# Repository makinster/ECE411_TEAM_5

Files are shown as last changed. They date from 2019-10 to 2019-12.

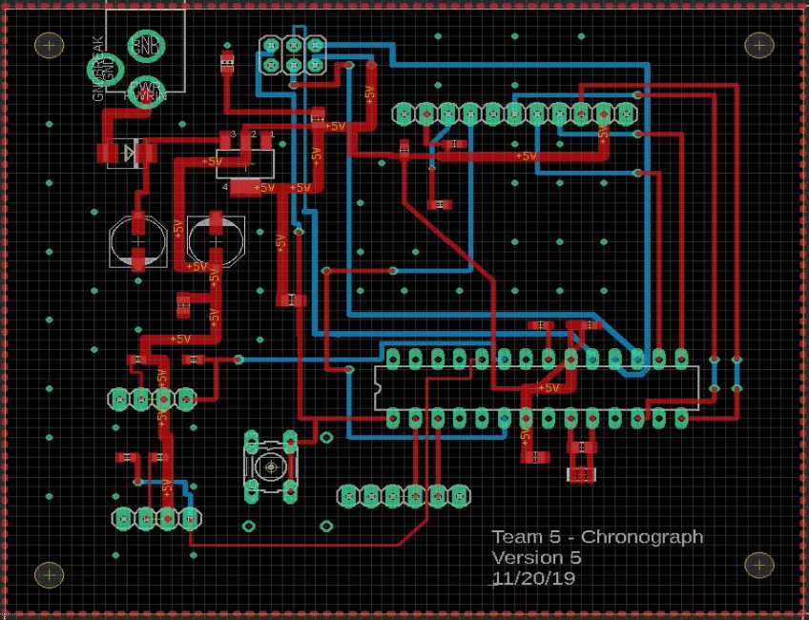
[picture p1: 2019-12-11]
Design Log/5_Implemtation - Board.PNG

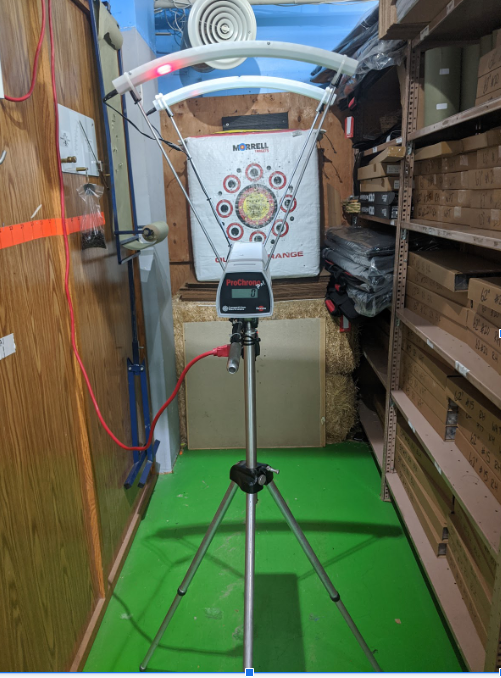
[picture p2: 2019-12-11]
Design Log/6_Testing at Archers Afield.PNG

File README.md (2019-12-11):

# ECE411 Team 5
Team 5 Project - Shooting Chronograph
Members: Sean Schorzman, Kelly Makinster, Jaeyoon Lee, Jianyu Hao

https://drive.google.com/drive/u/1/folders/1vWiaBcHWNWfePrjI9KzBYRflg-hPmRDC

**************************************************************************************

   Practicum project - Ballistic Chronograph
   
   ECE 411
   Fall 2019
   
   Team 5: Sean Schorzman, Jaeyoon Lee, Jianyu Hao, Kelly Makinster
                                                                                     
   Description: Displays the speed in fps of an object that passes through a
                set of IR detector sensors. IR sensors are arranged in a PVC
                pipe 8 inches apart with an IR light directily accross from
                each sensor. Upon passing sensor 1, a timer begins and waits
                until either sensor 2 detects an object or a timeout occurs.
                An additional push button input is used to reset IR detector
                light levels in order to adjust detection sensitivity.
                                                                                  
                                                                                  
 **************************************************************************************

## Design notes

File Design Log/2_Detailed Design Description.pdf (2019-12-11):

Module | Shooting Chronograph
Inputs | IR Sensor 1, IR Sensor 2, Power - USB
Outputs | LCD Screen, Sensor Output (Time between clocks)
Functionality | A flying projectile (BB, dart) will pass sensor 1. start clock, pass sensor 2, stop the clock. The time passed between the sensor interruptions will be displayed on an LCD screen

Shooting Chronograph: Level 0

Visual Paradigm Online Diagrams Express Edition

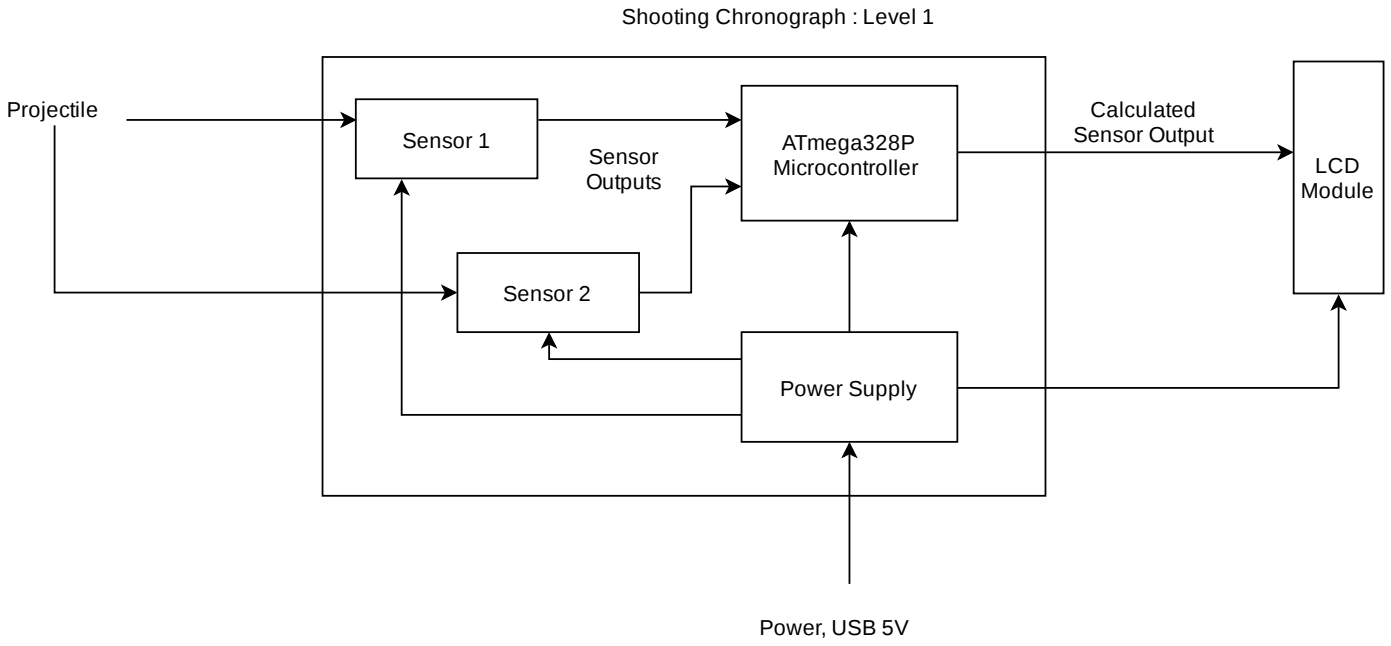
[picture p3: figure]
Power Supply; ATmega328P Microcontroller; Sensor 2; Sensor 1; Sensor Outputs; Calculated Sensor Output; Projectile; LCD Module; Shooting Chronograph : Level 1; Power, USB 5V

IR Sensor 1

Power
Supply
Projectile | Sensor Output
Module(s) | IR Sensor 1 / IR Sensor 2
Inputs | Projectile
Outputs | Sensor Output sent to ATmega328P Microcontroller

Functionality

The sensor will change sensor value if a projectile blocks emitter-detector communication

ATmega 328P
Microcontroller

Sensor 1 Output

Sensor 2 Output

Power
Supply

Calculated
Sensor Output
Module | ATmega 328P Microcontroller
Inputs | IR Sensor 1 and IR Sensor 2 Outputs
Outputs | Calculated Sensor Output - Velocity of Projectile
Functionality | The microcontroller will start the clock when sensor 1 is interrupted, and stop the clock once sensor 2 is interrupted. The microcontroller will calculate the speed of the projectile and send that data out.

LCD

Speed of
Projectile

Power
Supply

Calculated
Sensor
Output
Module | LCD

Power Supply

USB

5 DC Volts

Power Supply: Level 1

IR Sensor 1 and Sensor 2: Level 1

LCD Display: Level 1

ATmega 328P Microcontroller: Level 1

Module | Power Supply

Inputs | Microcontroller Sensor Calculations
Outputs | Speed of Projectile

Functionality

The LCD screen will display the speed of the projectile.

Inputs | USB
Outputs | 5 DC Volts

Functionality

Power supply via
USB Cable

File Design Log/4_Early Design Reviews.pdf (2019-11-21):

ECE 411

Practicum Week 7 HW Part 1

Design Reviews

Team 5: Jianyu Hao, Jaeyoon Lee, Kelly Makinster, Sean Schorzman

11/20/19

From Group 17:

- AVCC needs power + cap to ground
- AREF needs cap to ground
- LCD Pin 10 needs Volts
- Give names to J2

From Eric

- Make sure Team name, date, version is on silk screen
- Thicken 5V
- Trace 0 – ground supplies – Fix it
- Refer to AREF datasheet
- Power regulator needs to take in 5 volts
- 6 pin header and Display LCD should be separated a little

From Andrew:

- 100 nF cap AREF – cap to ground
- Bypass AVCC – cap to ground
- Ground symbol for each LCD
- Via ‘GND’ stitch two ground planes
- Din - +doc – dimensions
- J2 Blue wire – change top larger (Red)
- PD2 – serial adapter – delete Pin 1 on J2
- Bypass cap literally next to Pin C6
- Drill holes too small – Make larger

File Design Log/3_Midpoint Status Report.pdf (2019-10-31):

ECE 411

Practicum Homework #4: Current Status Report

Team 5: Jianyu Hao, Jaeyoon Lee, Kelly Makinster, Sean Schorzman

10/30/19

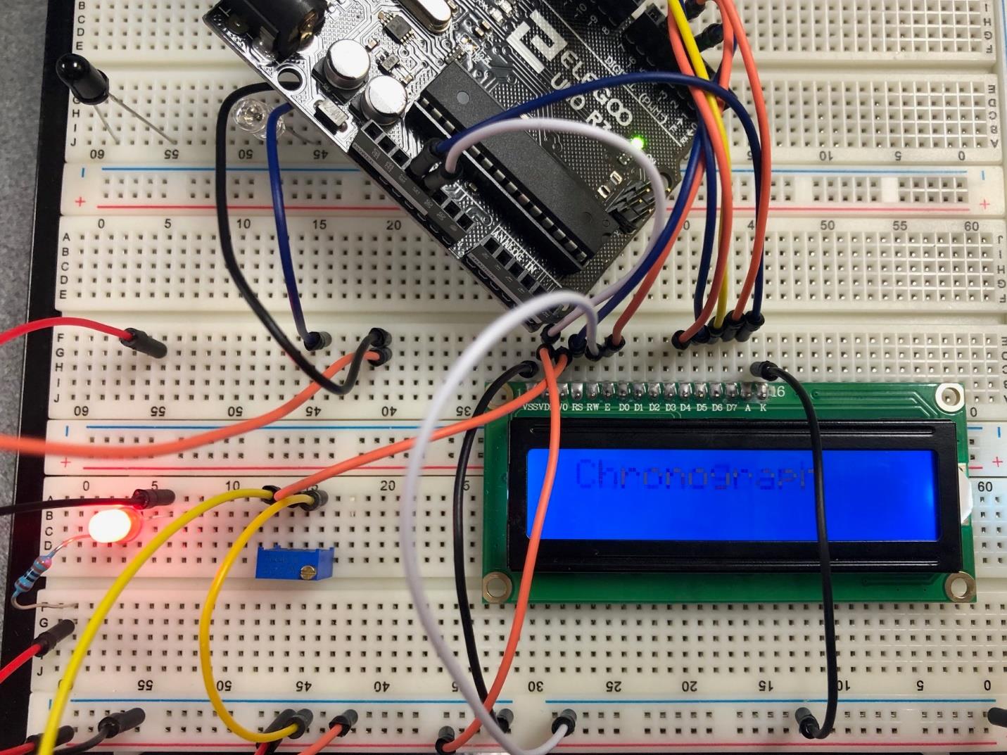
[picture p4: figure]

Our team has acquired most of the essential parts needed for the project in time to be assembled. We have also ensured the parts’ functionality to make sure they work when assembled on the breadboard together. With the preliminary schematic designed for our project, we built our first prototype on a breadboard at its rough stage. Currently, we’ve completed most of the assembly and double checked to make sure the parts function as they should. More research will be conducted in the upcoming week to complete the prototype and begin the first testing.

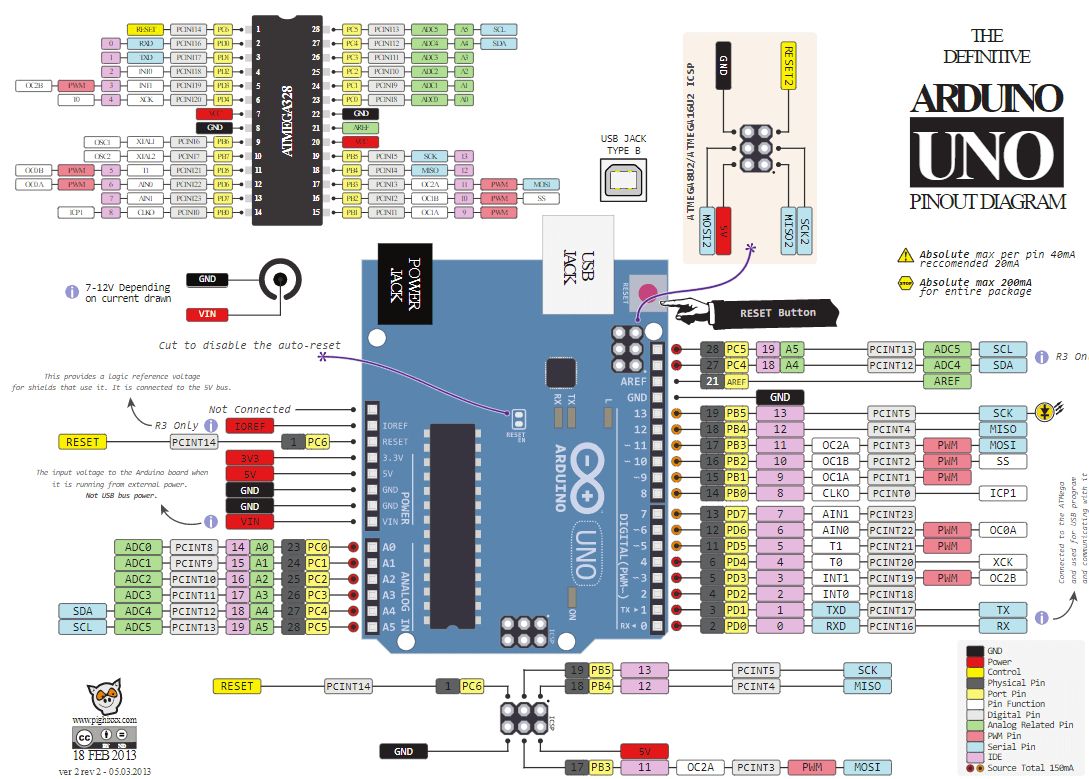
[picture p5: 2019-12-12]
Arduino Pinout.png

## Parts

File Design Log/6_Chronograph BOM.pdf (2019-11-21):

Chronograph BOM

Qty | Value | Parts | Manufacturer | Mfr. Part Number | Description
6 | 100n | C2, C4, C5, C6, C7, C8 | Samsung | CL21B104KBCNNNC | CAP CER 0.1UF 50V X7R 0805
2 | 47u | C1, C3 | NICHICON | UWT1H470MCL1GS | CAP ALUM 47UF 20% 50V SMD
1 | 10 | R11 | Yageo | RC0402FR-0710RL | RES SMD 10 OHM 1% 1/16W 0402
1 | 100 | R12 | Yageo | RC0402FR-07100RL | RES SMD 100 OHM 1% 1/16W 0402
2 | 1K | R3, R6 | Yageo | RC0805FR-071KL | RES SMD 1K OHM 1% 1/8W 0805
3 | 10K | R1, R13, R10 | Yageo | RC0805FR-0710KL | RES SMD 10K OHM 1% 1/8W 0805
1 | 1M | R2 | Yageo | RC0402FR-071ML | RES SMD 1M OHM 1% 1/16W 0402
1 | 3x2 M | J1 | Harwin Inc. | M20-9980346 | CONN HEADER VERT 6POS 2.54MM
1 | 1x6 | J2 | Würth Elektronik | 61300611121 | CONN HEADER VERT 6POS 2.54MM
2 | 1x4 | IR_PAIR1, IR_PAIR2 Würth Elektronik | 61300411121 | CONN HEADER VERT 4POS 2.54MM
1 | | R_BUTTON | B3F-1000 | OMRON SWITCH
1 | ATMEGA328P-PU | U4 | Microchip Technology | ATMEGA328-PU | IC MCU 8BIT 32KB FLASH 28DIP
1 | CSTCE16M0V53-R0 16MHZ | X1 | Murata Electronics | CSTCE16M0V53-R0 | CERAMIC RES 16.0000MHZ 15PF SMD
1 | EA_DIP | DIS1 | Lumex Opto/Components Inc. | LCM-S01602DTR/M | LCD MODULE 16X2 CHARACTER
1 | GREEN | LED1 | Würth Elektronik | 150080GS75000 | LED GREEN CLEAR 0805 SMD
1 | M7 | D1 | Diodes Incorporated | B340AE-13 | DIODE SCHOTTKY 40V 2A SMA
1 | NCP1117ST50T3G | U1 | ON Semiconductor | MC33375ST-5.0T3G | IC REG LINEAR 5V 300MA SOT223
2 | SFH206 | D6, D7 | Vishay Semiconductor Opto Division | BPW24R | SENSOR PHOTODIODE 900NM RADIAL
2 | SFH482 | D2, D3 | Vishay Semiconductor Opto Division | TSPF6200 | EMITTER IR 890NM 100MA RADIAL
1 | POWER_JACK | J4 | CUI Devices | PJ-102B | CONN PWR JACK 2.5X5.5MM SOLDER

PARTS NOT FROM DIGIKEY
PARTS ALREADY OWNED

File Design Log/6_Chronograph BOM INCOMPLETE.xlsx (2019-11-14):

Qty | Value | Device | Manufacturer | Parts | Mfr. Part Number | Description | Device
1 |  | PINHD-1X6 |  | J2 |  | PIN HEADER | PINHD-1X6
6 |  | R-US_0204/7 |  | R4, R5, R6, R7, R8, R9 |  | RESISTOR, American symbol | R-US_0204/7
2 | 100n | C-EUC0805 | SAMSUNG | C2, C6 | CL21B104KBCNNNC | CAP CER 0.1UF 50V X7R 0805 | C-EUC0805
1 | 10K | R-US_R0805 |  | R1 |  | RESISTOR, American symbol | R-US_R0805
1 | 1K | R-US_R0805 |  | R3 |  | RESISTOR, American symbol | R-US_R0805
1 | 1M | R-US_R0805 |  | R2 |  | RESISTOR, American symbol | R-US_R0805
1 | 3x2 M | PINHD-2X3 |  | J1 |  | PIN HEADER | PINHD-2X3
2 | 47u | CPOL-EUD | NICHICON | C1, C3 | UWT1H470MCL1GS | CAP ALUM 47UF 20% 50V SMD | CPOL-EUD
1 | ATMEGA328P-PU | ATMEGA328P-PU |  | U4 |  | MICROCONTROLLER | ATMEGA328P-PU
1 | CSTCE16M0V53-R0 16MHZ | RESONATORMU |  | X1 |  |  | RESONATORMU
1 | EA_DIP | EA_DIP |  | DIS1 |  | LCD-MODUL 2x16 - 6,68mm, INKL. KONTROLLER HD44780 | EA_DIP
1 | GREEN | LEDCHIP-LED0805 |  | LED1 |  | LED | LEDCHIP-LED0805
1 | M7 | DIODE-SMB |  | D1 |  | DIODE | DIODE-SMB
1 | NCP1117ST50T3G | MC33269ST-3.3T3 |  | U1 |  | Adjustable Output Low Dropout Voltage Regulator 800 mA | MC33269ST-3.3T3
1 | PC16S | PC16S |  | 20K |  | POTENTIOMETER | PC16S
1 | POWER_JACK | POWER_JACK |  | J4 |  | Power Jack Connector | POWER_JACK
4 | SFH482 | SFH482 |  | D2, D3, D4, D5 |  | IR LED | SFH482
4 | STAND-OFF | STAND-OFF |  | H1, H2, H3, H4 |  | Stand Off | STAND-OFF
1 | CRYSTAL 16.000 MHZ 18PF SMD |  |  |  |  | ECS-160-18-5PX-TR | ECS

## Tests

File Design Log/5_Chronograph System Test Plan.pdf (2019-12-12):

# ECE 411 Team #5

# Shooting Chronograph HW#7: Test Plan Rev.1

## Sean Schorzman Jaeyoon Lee Jianyu Hao Kelly Makinster

# Fall 2019

12/6/19

Table of Contents

1.0 | INTRODUCTION | 3
1.1. | This Document | 3
1.2. Conduct of the System Tests
3
1.3. | Recording of Results, Witnessing, and Authorities | 3
2.0 | REFERENCE DOCUMENTS | 3
2.1.1. PDS, Rev. 1
2.1.2. IR Light Level Code Rev. 0
2.1.3. Block Diagram Level 1, Rev. 1
2.2 | Design Documentation | 4
- Chronograph PDS | Rev. 1
- Block Diagram Level 1, Rev. 1
- Chronograph Schematic Rev. 5
- High Quality Chronograph Test Rev. 0
2.3 Other | 4
- Chronograph platform
- Ballistic testing tube
3.0 | Chronograph Overview | 4
3.1. Operational Description
3.2. Definition of Terminology
3.3. Display Methods
3.4. Computational Methods
- Distance over time (in FPS)
4.0 | Pretest Preparation | 5
4.1 | Test Equipment | 5
- Various Nerf Guns (different known velocities)
- Arduino IDE
- Testing tube (IR sensors attached)
- Multimeter
- Personal Computer
4.2 | Test Setup and Calibration | 5
5.0 | System Tests | 5
5.1. Functional Checks
5.1.1. Power Switch/Port and indicator Chronograph Schematic, rev. 5
5.1.2. Power supply voltage and current levels
5.1.2.1. Voltage regulator ~5V, ~1A
5.1.3. IR-SENSOR TEST Block Diagram, rev 0, PDS, rev. 1, IR Light Level Code Rev. 0
5.1.3.1. Initialization (Ready)
5.1.3.2. Signal strength check.
5.1.4. | RESET-TEST | Chronograph Schematic, rev. 5
5.1.4.1. Sensor Calibration
6.0 | Speed Range and Accuracy | 6

7.0 | Issues and Associated Risks | 6

### 1.0 Introduction

Shooting chronograph is a product that can measure a projectile speed that is travelling through a tube by measuring the time spent between a certain distance. It is a compact, light-weight device that can be mounted on a tripod and is powered by a 9V battery. It is ideally designed for recording Nerf gun darts.

### 1.1 This Document

This test plan briefly documents the process of testing the device using simple test cases.

### 1.2 Conduct of the System Tests

The system tests are primarily to check the functionality of the board. Will be done in a controlled environment to ensure personal performing tests are abiding by NFPA 70E guidelines for electrical safety in the workplace.

### 1.3 Recording of Results, Witnessing, and Authorities

Tests will be monitored and witnessed by multiple members to confirm the validity of the tests.

### 2.0 Reference Documents

The following documents are referenced in this test plan.

2.1.1. PDS, Rev 1
(https://github.com/makinster/ECE411_TEAM_5/blob/final/Design%20Log/1_PDS.pdf)
2.1.2. IR Light Level Code Rev. 0 (https://github.com/makinster/ECE411_TEAM_5/blob/final/Arduino%20Code/ECE411_IR_LIGHT_LEVEL_CODE) (https://github.com/makinster/ECE411_TEAM_5/blob/final/Arduino%20Code/ECE411_IR_LIGHT_LEVEL_CODE)
2.1.3. Block Diagram Level 1, Rev. 1 (https://github.com/makinster/ECE411_TEAM_5/blob/final/Block%20Diagrams/Block%20 Diagram%20Level%201.png) (https://github.com/makinster/ECE411_TEAM_5/blob/final/Block%20Diagrams/Block%20Diagram%20Level%201.png)
2.1.4. High Quality Chronograph Test Rev. 0

(https://github.com/makinster/ECE411_TEAM_5/blob/final/High%20Quality%20Chronogr aph%20Test) (https://github.com/makinster/ECE411_TEAM_5/blob/final/High%20Quality%20Chronograph%20Test)

### 2.2 Design Documentation

The following documents describe the design approach for the shooting chronograph.

- Chronograph PDS Rev.1
(https://github.com/makinster/ECE411_TEAM_5/blob/final/Design%20Log/1_PDS.pdf)
- Chronograph Block Diagram Level 1, Rev. 1 (https://github.com/makinster/ECE411_TEAM_5/blob/final/Block%20Diagrams/Block%20 Diagram%20Level%201.png) (https://github.com/makinster/ECE411_TEAM_5/blob/final/Block%20Diagrams/Block%20Diagram%20Level%201.png)
- Chronograph Schematic Rev. 5 (https://github.com/makinster/ECE411_TEAM_5/blob/final/FINAL%20FINAL%20ECE%2 0411%20Chronograph%20Schematic.sch) (https://github.com/makinster/ECE411_TEAM_5/blob/final/FINAL%20FINAL%20ECE%20411%20Chronograph%20Schematic.sch)

### 2.3 Other

Chronograph Platform:

Chronograph will be setup in an enclosure and the enclosure will be able to be set up on a tripod for stability control.

Testing Tube:

Testing tube will be used as a guide to ensure the sensors detect the projectile.

### 3.0 Chronograph Overview

3.1 Operation Description:

A projectile will be shot through the tube, sensor 1 will detect the projectile, start the timer, then sensor 2 will detect the projectile and stop the timer. The difference of the time will then be used put into an equation to determine the speed of which the object is going. The distance between sensors will be approx. 5 inch. Thus the ft/s will be given (5/12inch)/time difference.

3.2 Definition of Terminology

FPS - Feet per second is a standard term used to describe speeds of bullet, arrow and many more applicable projectile in the industry.

3.3 Display Methods

Visual display of the speed of the projectile will be displayed via LCD screen in FPS.

3.4 Computational Methods

ft/s will be given ( (5 inches) / (12 inches/foot) / ((stopTime-startTime) μs)(1E6 1/μs)

### 4.0 Pretest Preparation

Arduino code is loaded onto atMega microprocessor

### 4.1 Test Equipment

- Various Nerf Guns (different known velocities)
- Arduino IDE (Installed on PC)
- Testing tube (IR sensors attached)
- Multimeter for testing voltage output
- Personal Computer

### 4.2 Test Setup and Calibration

Tests are carried out to check the device’s functional test of essential components (power and IR sensors) and as well as the reset button that is soldered onto the board.

### 5.0 System Tests

5.1. Functional Checks
5.1.1. Power Switch/Port and indicator

When we turn on the power switch the green LED near the power switch should light up and the LCD display should light up as well. Visually check for confirmation that the power switch is working and components are getting power supplied to them.

5.1.2 Power Supply Voltage and Current Levels

Verify that all parts on the board on not receiving more than 5V and current that is not burning parts up.Check visually and make sure no products smell like they burnt out. Check voltage with multimeter.

5.1.3 IR Sensor Test (Test ID: IR-SENSOR TEST)

5.1.3.1 Initialization (Ready)

Verify visually that when the system goes from off state to on state that the system initially goes from reset state to ready state via LCD display and that analog values are displayed.

5.1.3.2 Signal Strength Check

Tests the IR Pair sensors to ensure that they are triggering when acceptable. Lower analog value means detection. Do this by blocking the IR pair and observing that the value on the LCD changes

5.1.4 RESET-TEST (Test ID: RESET-TEST)

5.1.4.1 Sensor Calibration

In case of unusual recordings and/or sensor malfunction (alignment error), on-board reset button recalibrates the sensors

### 6.0. Speed Range and Accuracy

Speed Range: Determined by blocking both sensors at the same time and reading the display via LCD.

Accuracy: Refer to High Quality Chronograph Test Document to compare values (https://github.com/makinster/ECE411_TEAM_5/blob/final/High%20Quality%20Chronogr aph%20Test) (https://github.com/makinster/ECE411_TEAM_5/blob/final/High%20Quality%20Chronograph%20Test)

### 7.0 Issues and Associated Risks

The following issues and risks can occur while testing the chronograph.

- The second sensor may not be able to detect the projectile and make no recording.
- The projectile must be shot straight otherwise precise measurement can’t be made.
- Wires may get disconnected if not handled with care.
- Battery will run out if power switch is left on continuously (use wall outlet to bypass this issue)

Chronograph: Test cases

Test Writer: Team 5

Test Case Name: | IR Sensors Test | Test ID: | IR-SENSOR TEST
Reference Doc. | Block Diagram, rev 0 ; PDS, rev. 1, IR Light Level Code Rev. 0
Description: | Tests the IR Pair sensors to ensure that they are triggering when acceptable. Lower analog value means detection. | Type | Black Box

Tester Information:

Name of Tester | | Date:
Hardware Ver: | 1.0 | Time:
Setup: | Make sure that the system is started from an off state Upload Arduino code to read analog values of IR sensors
step | Action | Expected Result | Pass | Fail | N/A | Comments
1 | Nothing | Displays equilibrium analog values of sensors
2 Block IR | Pair 1 | Displays lower analog value of IR pair 1
3 Unblock IR | Pair 1 | Returns to equilibrium analog value of IR pair 1
4 Block IR | Pair 2 | Displays lower analog value of IR pair 2
5 Unblock IR | Pair 2 | Returns to equilibrium analog value of IR pair 2

Overall Test Results:

Test Writer: Team 5

Test Case Name: | Reset Test | Test ID: | RESET-TEST
Reference Doc. | Chronograph Schematic, rev. 5
Description: | In case of unusual recordings and/or sensor malfunction, on-board Reset button recalibrates the sensors | Type | Black Box

Tester Information:

Name of Tester | | Date:
Hardware Ver: | 1.0 | Time:
Setup: | Make sure that the system is started from an off state
step | Action | Expected Result | Pass | Fail | N/A | Comments
1 | Nothing | Device starts in ready state Display says: “Ready”
2 Cross | sensor 1 | Device moves to waiting state Display says: “Started…”
3 Nothing | (for .5 sec) | Device times out Displays says: “Error”
4 | Reset | Reset BTTN is pushed Display says: “Ready”

Overall Test Results:

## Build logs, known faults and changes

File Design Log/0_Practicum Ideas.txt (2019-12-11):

Practicum Idea 

1.) Draw Pad -
The draw pad will use sensors (touch sensors?) that captures some form of contact and will record 
the contact movements and will either display them on a screen or a panel of LEDs will show the display. 
Using a microcontroller to output the movements to an LED display.

2.) Chronograph -
The chronograph will measure the time an object travles between two IR gates and calculate velocity.
Then the machine will display its result on an LED screen. 

Our group decides that the practicum project will be the chronograph. Final Decision. 

3.) USB power-ometer
This gadget will measure the voltage and amperage that flows between a simple USB port to the other USB port.
When the device is connected to a power source and the device that is being recharged through an USB port,
the seven segment display will show the voltage and current values in real time. 

4) Water Heater/kettle
This device will be comprised of three elements: a temperature probe, heating element and leds for feedback.
The device will be used to heat up a beaker of water. The temperature of the water will be measured and displayed
on a set of leds. There will be 4 leds which correspond to 5, different states: off, heat on but cold, heat on but
medium, heat on and hot, and heat on and boiling. When the device reaches a boiling temperature, it will begin to 
toggle between a heating on state and a heating off state in order to maintain the water's temperature.

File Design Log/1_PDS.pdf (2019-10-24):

ECE 411
Practicum Homework #3: Product Design Specification (PDS)/Requirements Team 5: Jianyu Hao, Jaeyoon Lee, Kelly Makinster, Sean Schorzman 10/24/2019

## Product: Shooting Chronograph

This device will capture velocity of objects that pass through a predetermined area.

Chronographs are popular amongst hunters and marksman alike who want to measure the

velocity of the bullets fired from their weapons. This will be used to increase shooting

performance and analysis. The user will present an object and have it pass through an area,

whether that be fired from a weapon, thrown by the user, or by a machine.

Intended customers will be researchers, athletes, airsoft enthusiasts who need to

measure the speed of an object that passes through the chronograph for personal interest,

safety, and more.

Currently there are chronograph manufacturers in the market that are usually priced high

and offer only a small sized object to pass through its device. Professional chronograph that

measure extremely fast moving object costs well over $100. Using our own equipment and

parts, we believe we can market our chronograph as the affordable chronograph that can

measure a reasonable range of speeds. We believe we can offer a competitive price at $30/unit.

- The Chronograph must be portable.
- It should be powered by a USB port.
- It must be able to measure as slow as 70 ft/s (Nerf dart)
- It must be able to measure speeds up to 250 ft/s (arrow speed)
- It may be able to measure speeds up to 2500 ft/s (rifle bullet speed)

1 Ver. 1

- The chronograph must have a built in screen to display speeds
- The chronograph should have an enclosure so that it can be mounted on a tripod
- The chronograph must be safe to use (ie: no sharp edges on design)

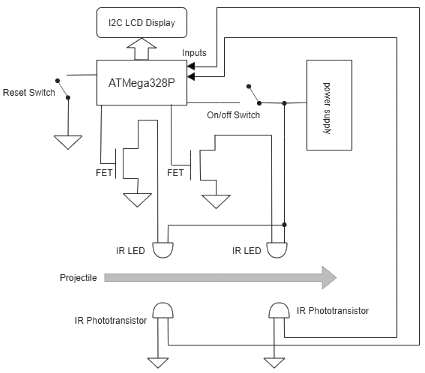
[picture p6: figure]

Design Specification:

- Minimum of 2 optical sensors IR Phototransistor: IR Emitter/Detector pair x2
- Processor
ATMega328P
- Actuator
Digital Display Screen: 16x2 I2C LCD Display
- Power
Low Power Consumption, voltage supplied by USB or battery (9V) Operating Voltage: 1.8-5.5 volts
- Firmware
Code written in C
- Development environment
Interface with CPU using AVR Dragon Use ATMEL Studio IDE
EAGLE CAD
- Product Lifespan
1-2 years
- Accuracy
+/- 10% of object’s known speed
- Temperature Range
-40 to 150+ C
-40 to 257+ F

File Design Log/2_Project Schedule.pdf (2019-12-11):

ID | Task Mode | Task Name | Duration | Start | Finish | PredecessorsResource Names
1 | | Week 1 - Research | 5 days | Thu 03/10/19Wed 09/10/19
2 | Team forming | 2 days | Thu 03/10/19Fri 04/10/19 | Jaeyoon,Kelly,Oscar,Sean
3 | Exchange contacts | 1 day | Mon 07/10/19Mon 07/10/19 | | 2 | 2
4 | Assign roles | 1 day | Tue 08/10/19Tue 08/10/19 | | 3 | 3
5 | Check team on D2L | 1 day | Wed 09/10/19Wed 09/10/19 | | 4 | 4
6 | Week 2 - Brainstorming | 5 days | Thu 10/10/19 | Wed 16/10/19 | 1 | 1
7 | Create Collaboration site | 2 days | Thu 10/10/19Fri 11/10/19 | | | Sean
8 Have everyone join group | Github | 1 day | Fri 11/10/19 | Fri 11/10/19 | | Jaeyoon,Kelly,Oscar,Sean
9 | brainstorm for project ideas | 2 days | Mon 14/10/19Tue 15/10/19 | | | Jaeyoon,Kelly,Oscar,Sean
10 | Submit HW #2 | 1 day | Wed 16/10/19Wed 16/10/19 | | | Sean
11 | Week 3 - Product Requirements | 5 days | Thu 17/10/19Wed 23/10/19 | | 6 | 6
12 | Research on project idea | 5 days | Thu 17/10/19Wed 23/10/19 | | | Kelly,Sean ,Jaeyoon,Oscar
13 | Google collaboration document3 days | | Fri 18/10/19 | Tue 22/10/19 | | Jaeyoon,Kelly,Oscar,Sean
14 Order parts needed for the | project | 5 days | Thu 17/10/19 | Wed 23/10/19 | 6 | 6
15 | Week 4 - Prototype | 5 days | Thu 24/10/19Wed 30/10/19 | | 11 | 11
16 | Build the first prototype | 5 days | Thu 24/10/19Wed 30/10/19 | | | Jaeyoon,Kelly,Sean
17 Eagle CAD preliminary | schematic | 3 days | Mon 28/10/19 | Wed 30/10/19 | | Sean
18 | Check parts for functionality | 2 days | Tue 29/10/19Wed 30/10/19 | | | Jaeyoon,Oscar
19 | Write up report and submit to TA1 day | | Wed 30/10/19Wed 30/10/19 | | | Jaeyoon
20 | Week 5 - Product schedule | 5 days | Thu 31/10/19Wed 06/11/19 | | 15 | 15

Jaeyoon,Kelly,Oscar,Sean
Jaeyoon,Kelly,Oscar,Sean
Jaeyoon,Kelly,Oscar,Sean
30 | 03 | 06 | 09

October 2019

Task

Split

Milestone

Summary

Project Summary

Inactive Task

Inactive Milestone

Inactive Summary

Manual Task

Duration-only

Manual Summary Rollup

Manual Summary

Start-only

Finish-only

External Tasks

External Milestone

Deadline

Progress

Manual Progress

Page 1

Project: Simple Project Plan Date: Wed 11/12/19

| Mode
21 | | Downlod Microsoft Project | 2 days | Thu 31/10/19Fri 01/11/19 | | | Jaeyoon,Kelly,Oscar,Sean
22 | | Post to Github | 1 day | Mon 04/11/19Mon 04/11/19 | | | Oscar
23 | | Adjust schedule | 2 days | Tue 05/11/19Wed 06/11/19 | | | Jaeyoon,Kelly,Oscar,Sean
24 Send link to TA and submit to | | D2L | 1 day | Wed 30/10/19 | Wed 30/10/19 | | Jaeyoon
25 | | Week 6 - Detailed Design | 5 days | Thu 07/11/19Wed 13/11/19 | | 20 | 20
26 | | High level block diagram | 3 days | Fri 08/11/19 | Tue 12/11/19 | | Sean
27 | | Next level block diagram | 3 days | Mon 11/11/19Wed 13/11/19 | | | Kelly
28 | | Top level block diagram | 3 days | Mon 11/11/19Wed 13/11/19 | | | Jaeyoon
29 Send link to TA and submit to | | D2L | 1 day | Wed 13/11/19 | Wed 13/11/19 | | Oscar
30 | | Week 7 - Modelling | 5 days | Thu 14/11/19Wed 20/11/19 | | 25 | 25
31 | | UML physical view | 3 days | Fri 15/11/19 | Tue 19/11/19 | | Sean
32 | | UML class diagram | 2 days | Fri 15/11/19 | Mon 18/11/19 | | Kelly
33 | | UML case description | 2 days | Fri 15/11/19 | Mon 18/11/19 | | Jaeyoon
34 | | UML acitivty | 2 days | Tue 19/11/19Wed 20/11/19 | | | Oscar
35 | | Write specification | 1 day | Wed 20/11/19Wed 20/11/19 | | | Sean
36 | | Post on D2L | 1 day | Wed 20/11/19Wed 20/11/19 | | | Oscar
37 | | Week 8 - Testing plan | 5 days | Thu 21/11/19Wed 27/11/19 | | 30 | 30
38 | | Create test plan | 3 days | Fri 22/11/19 | Tue 26/11/19 | | Kelly,Sean
39 Create detailed test case | | descriptions | 3 days | Mon 25/11/19 | Wed 27/11/19 | | Jaeyoon,Oscar
40 | | Week 9 - Testing and Debugging | 5 days | Thu 28/11/19Wed 04/12/19 | | 25 | 25
41 | | Test chronograph - rough stage 5 days | | Thu 28/11/19Wed 04/12/19 | | | Sean
30 | 03 | 06 | 09

Task

Split

Milestone

Summary

Project Summary

Inactive Task

Inactive Milestone

Inactive Summary

Manual Task

Duration-only

Manual Summary Rollup

Manual Summary

Start-only

Finish-only

External Tasks

External Milestone

Deadline

Progress

Manual Progress

Page 2

Project: Simple Project Plan Date: Wed 11/12/19

| Mode
42 | | Check the demo piece | 5 days | Thu 28/11/19Wed 04/12/19 | | | Kelly,Oscar
43 | | Field testing | 5 days | Thu 28/11/19Wed 04/12/19 | | | Jaeyoon
44 Send link to TA and submit Test | | plan | 1 day | Wed 04/12/19 | Wed 04/12/19 | | Oscar
45 | | Week 10 - Prepping for Demo | 3 days | Thu 05/12/19Mon 09/12/19 | | 40 | 40
46 | | Check demo-ready pieces | 3 days | Thu 05/12/19Mon 09/12/19 | | | Jaeyoon,Kelly,Oscar,Sean
47 | | Finals Week - Demo | 5 days | Mon 09/12/19Fri 13/12/19 | | 45 | 45
48 | | Assign demo date | TBA
49 | | Demonstration of chronograph | TBA
30 | 03 | 06 | 09

Task

Split

Milestone

Summary

Project Summary

Inactive Task

Inactive Milestone

Inactive Summary

Manual Task

Duration-only

Manual Summary Rollup

Manual Summary

Start-only

Finish-only

External Tasks

External Milestone

Deadline

Progress

Manual Progress

Page 3

Project: Simple Project Plan Date: Wed 11/12/19

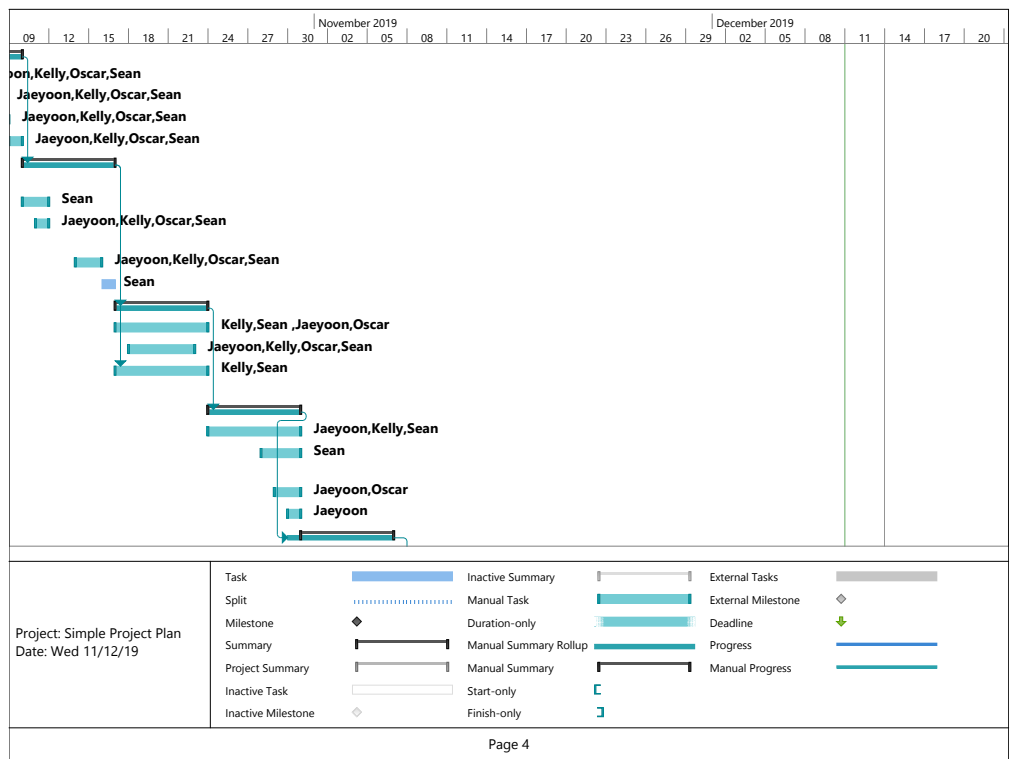
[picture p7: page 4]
Jaeyoon,Oscar; Jaeyoon; November 2019; December 2019; Task; Split; Milestone; Summary; Project Summary; Inactive Task; Inactive Milestone; Inactive Summary; Manual Task; Duration-only; Manual Summary; Start-only; Finish-only; External Tasks; External Milestone; Deadline; Progress; Manual Progress; Page 4

Jaeyoon,Kelly,Oscar,Sean

Sean

Kelly,Sean ,Jaeyoon,Oscar
Kelly,Sean

Jaeyoon,Kelly,Sean

Project: Simple Project Plan
Date: Wed 11/12/19

Manual Summary Rollup

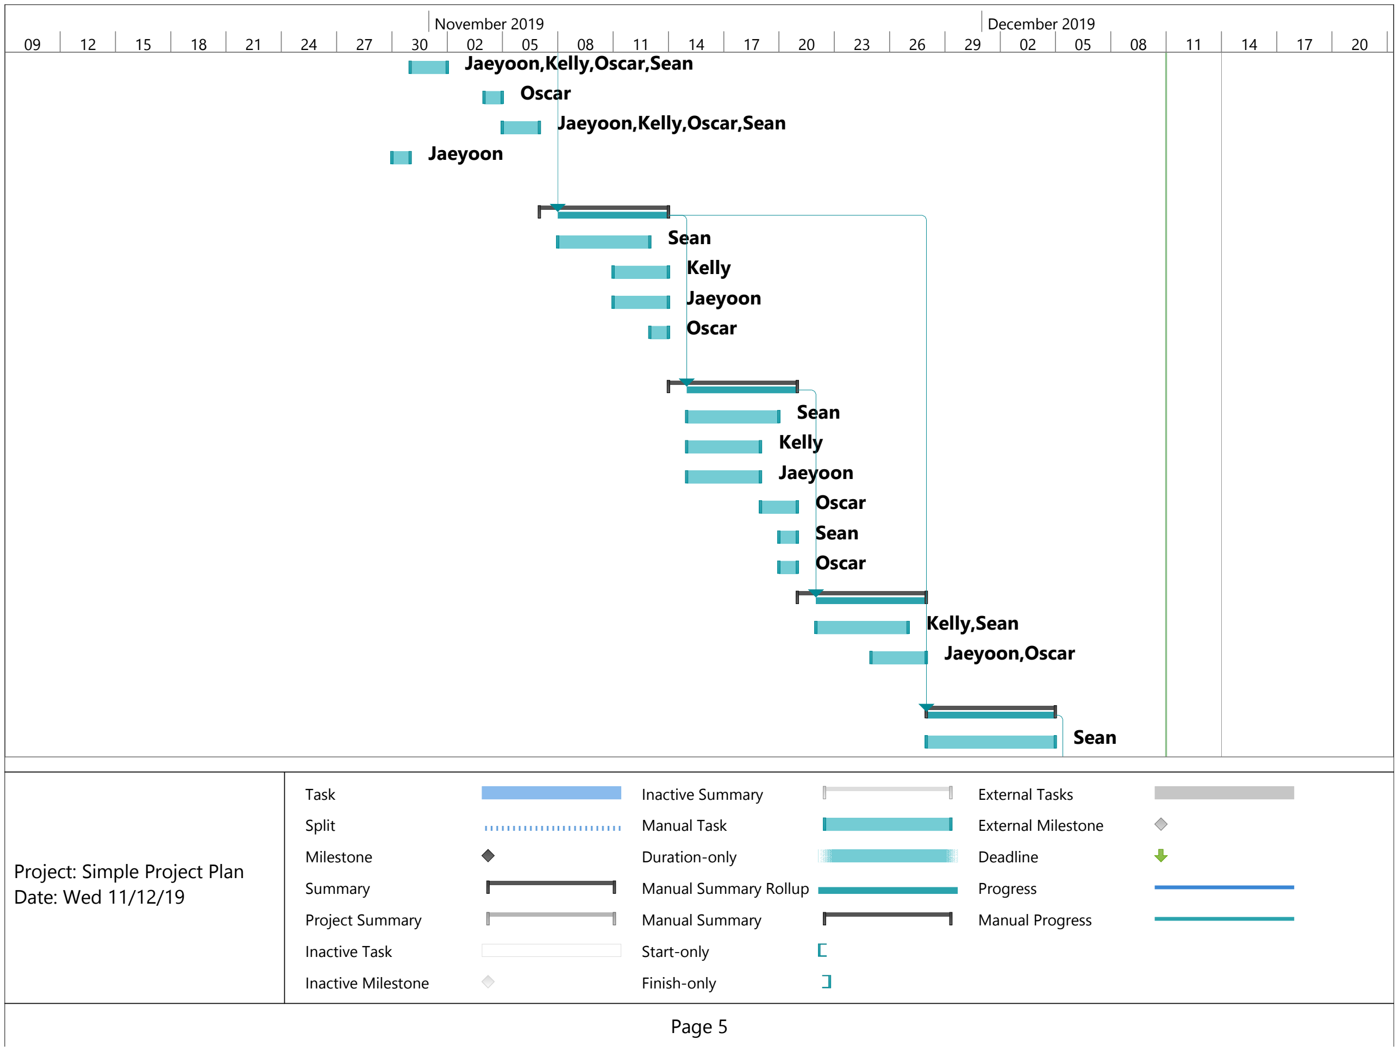
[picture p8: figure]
Jaeyoon,Kelly,Oscar,Sean; Oscar; Jaeyoon; Sean; Kelly Jaeyoon Oscar; Kelly; Kelly,Sean; Jaeyoon,Oscar; Task; Split; Milestone; Summary; Project Summary; Inactive Task; Inactive Milestone; Inactive Summary; Manual Task; Duration-only; Manual Summary Rollup; Manual Summary; Start-only; Finish-only; External Tasks; External Milestone; Deadline; Progress; Manual Progress; Page 5; Project: Simple Project Plan Date: Wed 11/12/19

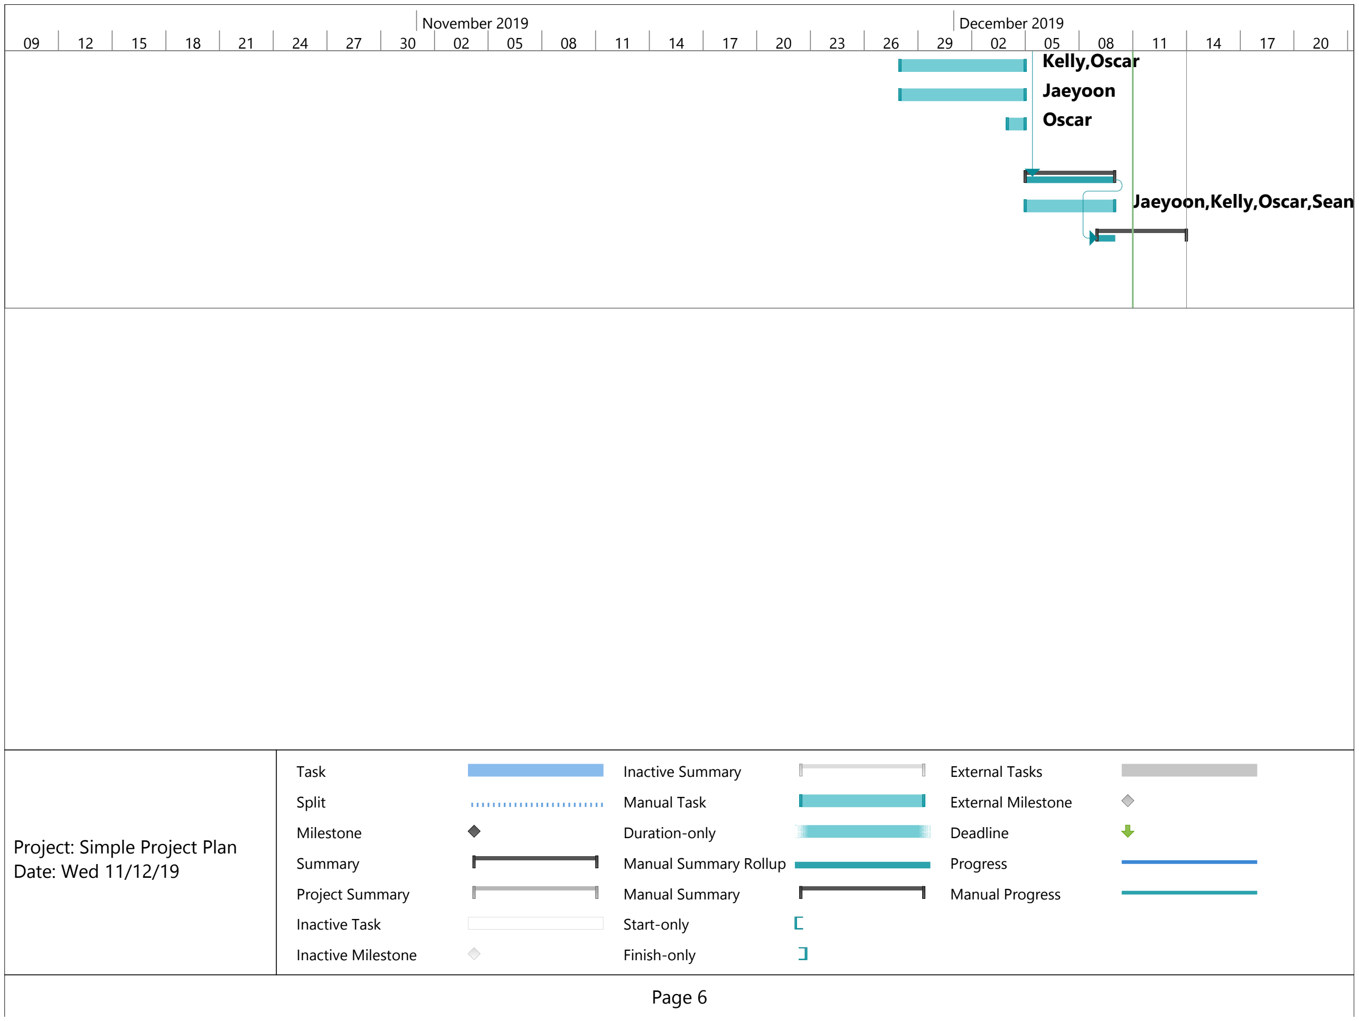
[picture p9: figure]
Kelly,Oscar; Jaeyoon; Oscar; Jaeyoon,Kelly,Oscar,Sean; Task; Split; Milestone; Summary; Project Summary; Inactive Task; Inactive Milestone; Inactive Summary; Manual Task; Duration-only; Manual Summary Rollup; Manual Summary; Start-only; Finish-only; External Tasks; External Milestone; Deadline; Progress; Manual Progress; Page 6; Project: Simple Project Plan Date: Wed 11/12/19

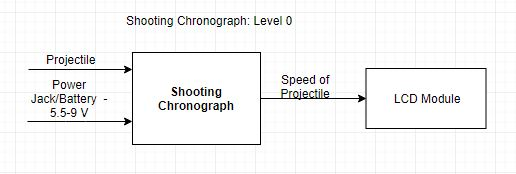
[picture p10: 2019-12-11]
Design Log/2_Block Diagram Level 0.png

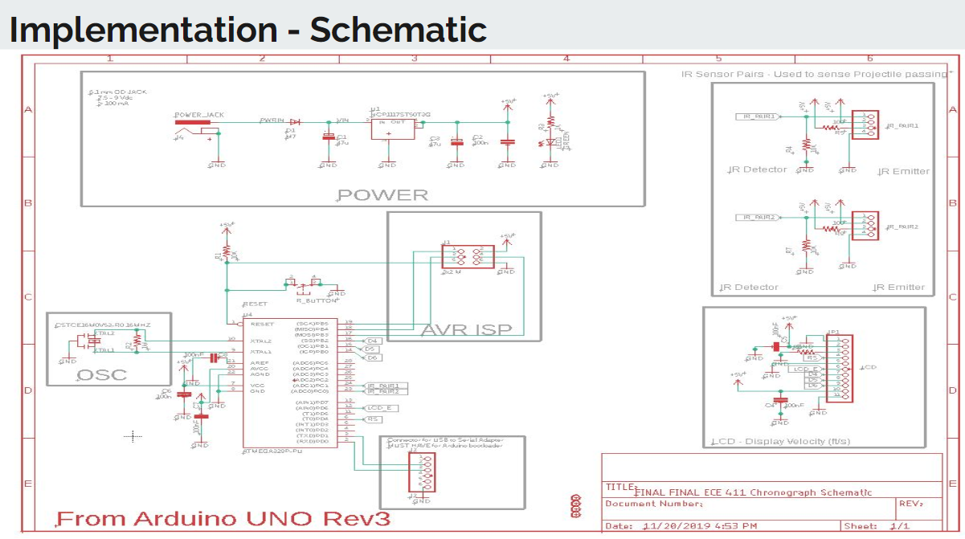
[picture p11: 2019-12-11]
Design Log/5_Implemtation - Schemtatic.PNG

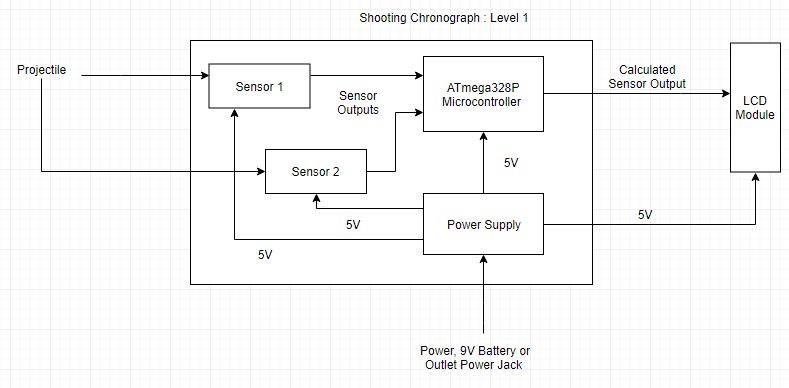
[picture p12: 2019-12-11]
Design Log/2_Block Diagram Level 1.png

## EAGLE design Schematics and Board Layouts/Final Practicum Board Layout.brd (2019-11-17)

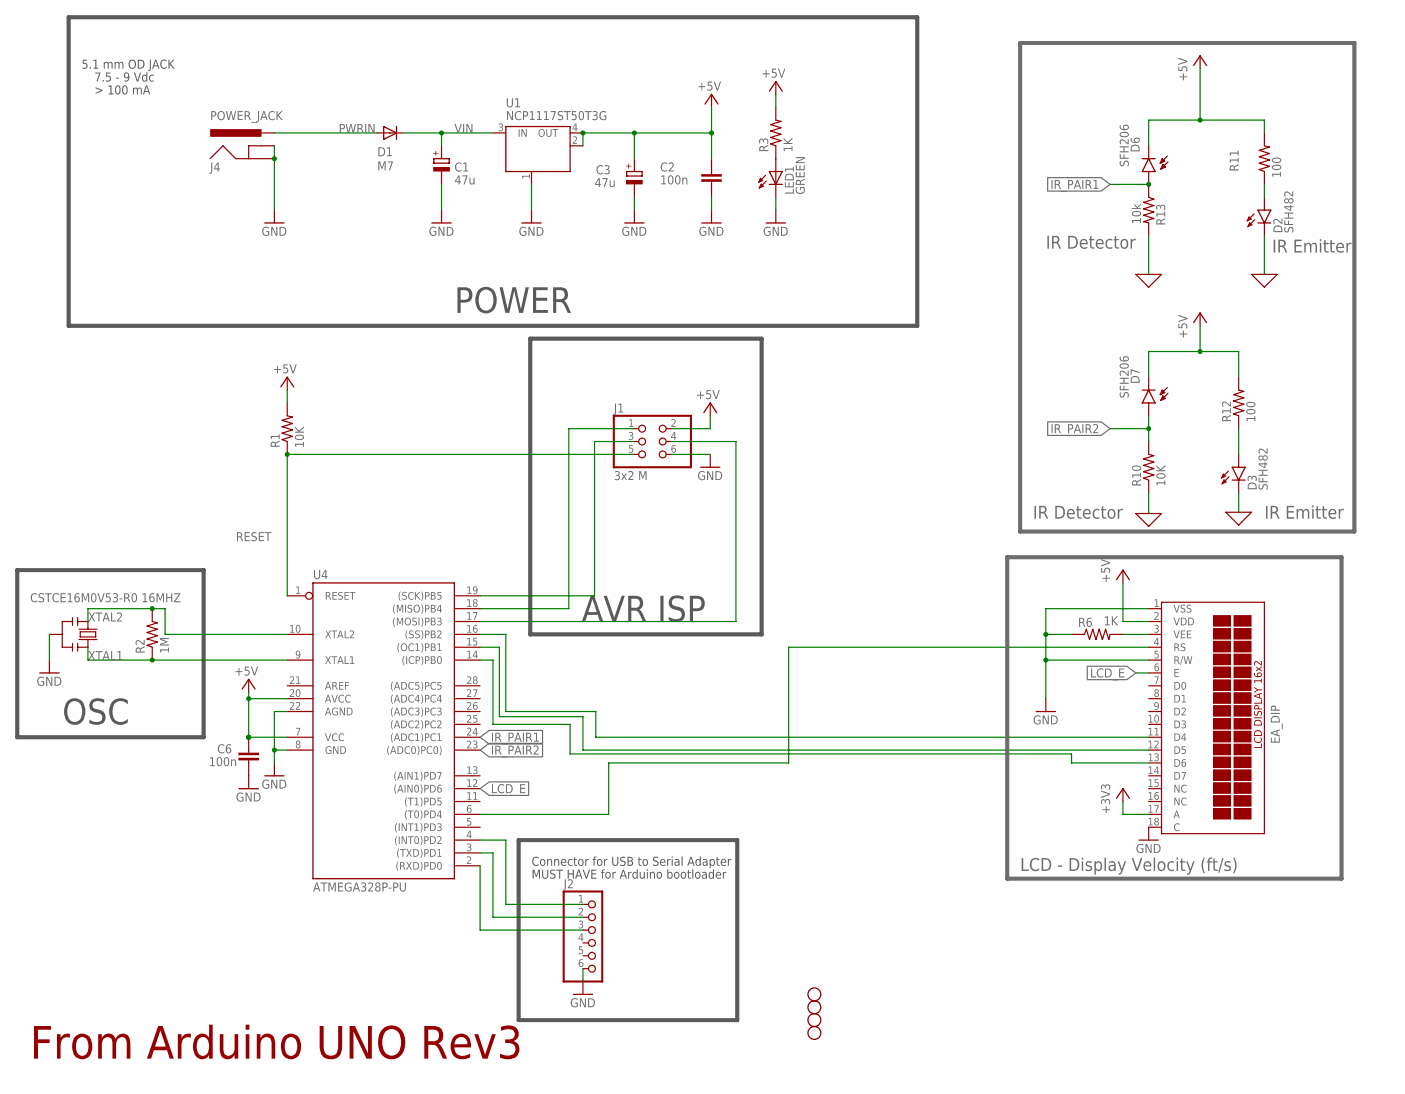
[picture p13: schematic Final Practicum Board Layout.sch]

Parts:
C1, C3: 47u; PANASONIC_D
C2, C6: 100n; C0805
D1: M7; SMB
D2, D3: SFH482
D6, D7: SFH206
DIS1: EA_DIP
H1, H2, H3, H4: STAND-OFF
J1: 3x2 M; 2X03
J2: PINHD-1X6; 1X06
J4: POWER_JACK; POWER_JACK_PTH
LED1: GREEN; CHIP-LED0805
R1: 10K; R0805
R2: 1M; R0805
R3: 1K; R0805
R6: 1K; R0603
R10: 10K; R0603
R11, R12: 100; R0603
R13: 10k; R0603
U1: NCP1117ST50T3G; SOT223
U4: ATMEGA328P-PU; DIL28-3
X1: CSTCE16M0V53-R0 16MHZ; RESONATOR

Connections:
0: D2.K (C), D3.K (C), R10.1, R13.2
+3V3: DIS1.17 (A)
+5V: C2.2, C3.+, C6.2, D6.K (C), D7.K (C), DIS1.2 (VDD), J1.2, R1.2, R3.2, R11.2, R12.2, U1.2 (OUT), U1.4 (OUT), U4.7 (VCC), U4.20 (AVCC)
GND: C1.-, C2.1, C3.-, C6.1, DIS1.1 (VSS), DIS1.5 (R/W), DIS1.18 (C), J1.6, J2.6, J4.GND, J4.GNDBREAK, LED1.C, R6.1, U1.1 (GND/ADJ), U4.8 (GND), U4.22 (AGND), X1.2
IR_PAIR1: D6.A, R13.1
IR_PAIR2: D7.A, R10.2
LCD_E: DIS1.6 (E)
MISO: J1.1, U4.18 ((MISO)PB4)
MOSI: J1.4, U4.17 ((MOSI)PB3)
unnamed: DIS1.4 (RS), U4.6 ((T0)PD4)
unnamed: DIS1.3 (VEE), R6.2
unnamed: LED1.A, R3.1
unnamed: J2.3, U4.2 ((RXD)PD0)
unnamed: DIS1.13 (D6), U4.14 ((ICP)PB0)
unnamed: DIS1.12 (D5), U4.15 ((OC1)PB1)
unnamed: DIS1.11 (D4), U4.16 ((SS)PB2)
unnamed: D2.A, R11.1
unnamed: J2.2, U4.3 ((TXD)PD1)
unnamed: J2.1, U4.4 ((INT0)PD2)
unnamed: D3.A, R12.1
PWRIN: D1.A, J4.PWR
RESET: J1.5, R1.1, U4.1 (RESET)
SCK: J1.3, U4.19 ((SCK)PB5)
VIN: C1.+, D1.C, U1.3 (IN)
XTAL1: R2.1, U4.9 (XTAL1), X1.3
XTAL2: R2.2, U4.10 (XTAL2), X1.1

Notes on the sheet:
From Arduino UNO Rev3
7.5 - 9 Vdc
POWER
AVR ISP
OSC
5.1 mm OD JACK
Connector for USB to Serial Adapter
MUST HAVE for Arduino bootloader
IR Detector
IR Emitter
LCD - Display Velocity (ft/s)

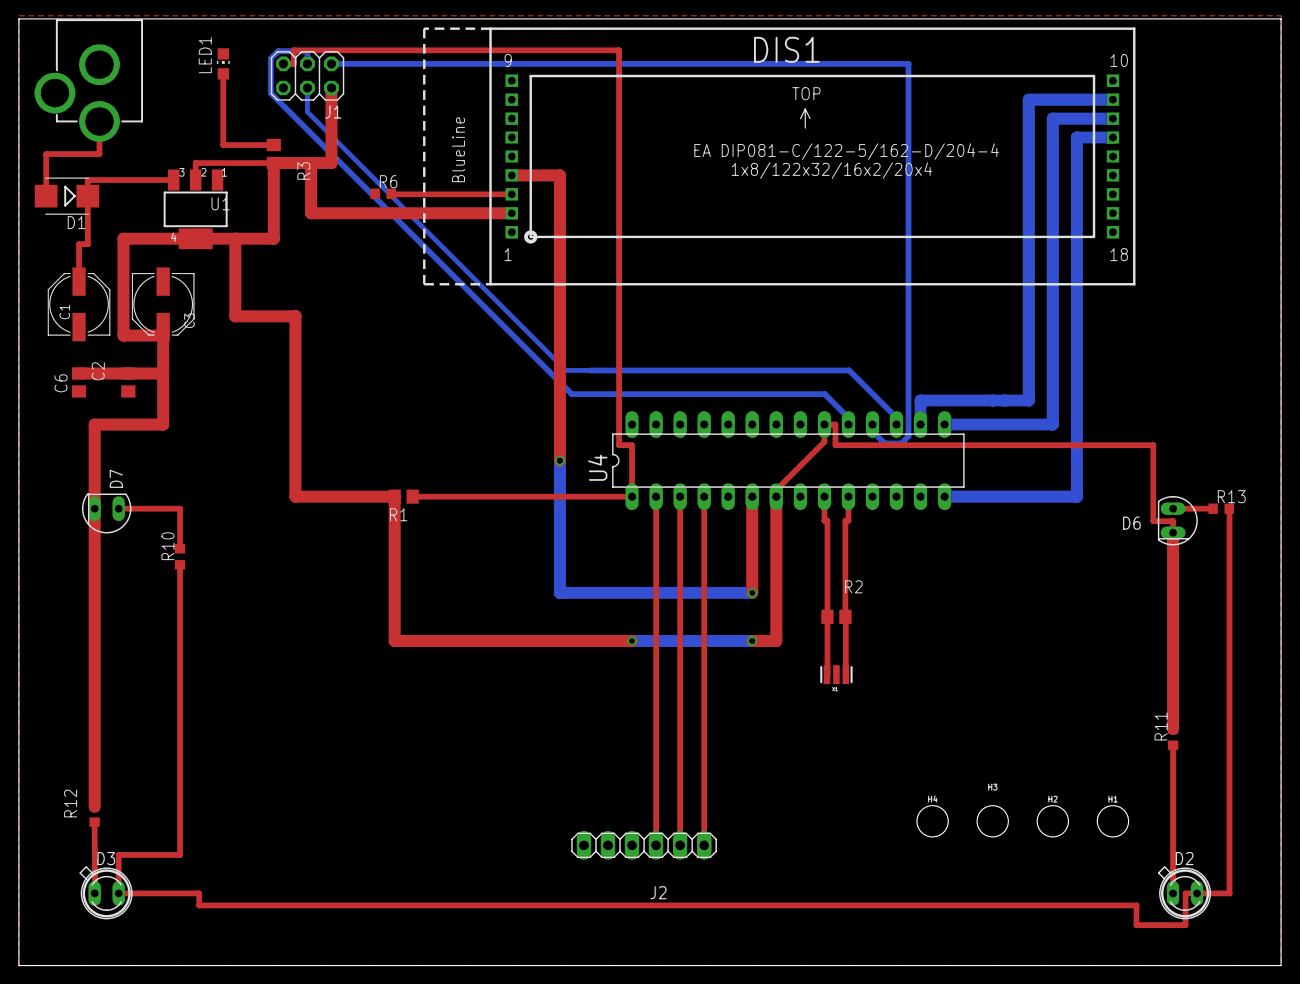
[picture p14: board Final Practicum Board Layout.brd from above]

Board: 2 copper layers, 133.3 x 100.0 mm, 29 parts (0 on the bottom side), 24 nets.

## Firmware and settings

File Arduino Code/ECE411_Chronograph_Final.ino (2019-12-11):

/**************************************************************************************
   Practicum project - Ballistic Chronograph
   ECE 411
   Fall 2019
   Team 5: Sean Schorzman, Jaeyoon Lee, Jianyu Hao, Kelly Makinster
                                                                                     
   Description: Displays the speed in fps of an object that passes through a
                set of IR detector sensors. IR sensors are arranged in a PVC
                pipe 8 inches apart with an IR light directily accross from
                each sensor. Upon passing sensor 1, a timer begins and waits
                until either sensor 2 detects an object or a timeout occurs.
                An additional push button input is used to reset IR detector
                light levels in order to adjust detection sensitivity.
                                                                                     
 **************************************************************************************/

#include <LiquidCrystal.h> //include the library code

//LCD pins
LiquidCrystal lcd(4, 6, 10, 9, 8, 7);

//Variables
int sensor1_read = A0;      //IR Detector 1 light level reading
int sensor2_read = A1;      //IR Detector 2 light level reading
unsigned long start_sensor; //Used to clock the time after sensor 1 is tripped
unsigned long stop_sensor;  //Used to clock the time after sensor 2 is tripped
float calculated;           //Used in the ballistic velocity calculation
long sensor_delay_counter;  //Used to display the current sensor light levels
int sensor1_threshhold;     //threshold to trip sensor 1
int sensor2_threshhold;     //threshold to trip sensor 2
int period = 3000;          //delay for 3 seconds
unsigned long time_now = 0; //used to store current time

//Functions
void lcd_sensor_values();   //displays sensor readings on line 2
void calculate_velocity(unsigned long start_sensor, unsigned long stop_sensor);

//this finction is used to set up the inputs and outputs used on the chronograph
void setup()
{
  lcd.begin(16, 2);  // set up the LCD's number of columns and rows
  Serial.begin(9600);
  pinMode(A0, INPUT);
  pinMode(A1, INPUT);
  pinMode(2, INPUT);
}

//this loop takes care of all sensor reads, timers and button presses.
void loop()
{
  lcd.clear();
  lcd.print("Ready");
  
  //****************************************
  //recalibrate sensors
  sensor1_read = analogRead(A0);
  sensor2_read = analogRead(A1);
  sensor1_threshhold = sensor1_read / 2.0;
  sensor2_threshhold = sensor2_read / 2.0;
  //****************************************
  
  lcd_sensor_values();                  //displays current sensor values
  sensor_delay_counter = 0;
  
  //wait for sensor 1 to be tripped or button press
  while ( (analogRead(A0) > sensor1_threshhold) && digitalRead(2) == LOW )
  {
    ++sensor_delay_counter;
    if (sensor_delay_counter == 5000)   //short delay before displaying sensor values
    {
      lcd_sensor_values();              //displays current sensor values
    }
  }

  if (digitalRead(2) == LOW)            //button wasn't pressed
  {
    time_now = millis();                //get current time for timeout delay
    lcd.clear();
    lcd.print("Started...");
    start_sensor = micros();  //get start time for when sensor 1 was tripped

    //remain in loop until sensor 2 is tripped, button is pressed or timeout has occured
    while ( ( analogRead(A1) > sensor2_threshhold ) && (millis() < time_now + period) && digitalRead(2) == LOW )
    {
      //empty loop
    }

    //if sensor 2 was tripped
    if (analogRead(A1) < sensor2_threshhold)
    {
      stop_sensor = micros();
      calculate_velocity(start_sensor, stop_sensor);
    }
    //if button was pressed
    else if (digitalRead(2) == HIGH)
    {
      lcd.clear();
      lcd.print("Reset...");
      delay(2500);
    }

    //timeout occured
    else
    {
      lcd.clear();
      lcd.print("Error");
      delay(1000);
    }

  }

  //button was pressed
  else
  {
    lcd.clear();
    lcd.print("Reset...");
    delay(1000);
  }
}


//this function is used to print out the current detector sensor light level on line 2
void lcd_sensor_values()
{
  lcd.clear();
  lcd.print("Ready");
  lcd.setCursor(0, 1);
  lcd.print("S1:");
  lcd.setCursor(3, 1);
  lcd.print(analogRead(A0));  // Print a message to the LCD.
  lcd.setCursor(8, 1);
  lcd.print("S2:");
  lcd.setCursor(11, 1);
  lcd.print(analogRead(A1));  // Print a message to the LCD.
  sensor_delay_counter = 0;
}

void calculate_velocity(unsigned long start_sensor, unsigned long stop_sensor)
{
  lcd.clear();
  calculated = (5.000 / 12.000) / ((stop_sensor - start_sensor) / 1000000.000);
  lcd.print(calculated);
  lcd.setCursor(5, 0);
  lcd.print("FPS");
  delay(2500);
}

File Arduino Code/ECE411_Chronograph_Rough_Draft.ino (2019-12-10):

  
//LCD Screen and IR Sensor

#include <LiquidCrystal.h>// include the library code
/**********************************************************/
//char array1[]=" Chronograph";  //the string to print on the LCD
//char array2[]="Practicum!";  //the string to print on the LCD

int tim = 100;  //the value of delay time
// initialize the library with the numbers of the interface pins

LiquidCrystal lcd(4, 6, 10, 9, 8, 7);
/*********************************************************/

int ifRead1 = A0;
int ifRead2 = A1;
long start;
long stop1;
float calculated;
long counter;
long counter2;

void setup()
{  
  lcd.begin(16, 2);  // set up the LCD's number of columns and rows
   
  Serial.begin(9600);
  pinMode(A0,INPUT);
  pinMode(A1,INPUT);
  pinMode(2, INPUT);
  }
/*********************************************************/

void loop()
{
  ifRead1 = analogRead(A0);
  ifRead2 = analogRead(A1);
  lcd.clear();
  lcd.print("Ready");

  counter = 0;
  counter2 = 0;
  
  while( (analogRead(A0) > (ifRead1/2.0)) && digitalRead(2)==LOW ) 
  {
     ++counter2;
     if (counter2 == 2000)
     {
         lcd.clear();
         lcd.print("Ready");
         lcd.setCursor(0,1);
         lcd.print("S1:");
         lcd.setCursor(3,1);
         lcd.print(analogRead(A0));  // Print a message to the LCD.
         lcd.setCursor(7,1);
         lcd.print("S2:");
         lcd.setCursor(10,1);      
         lcd.print(analogRead(A1));  // Print a message to the LCD.
         counter2 = 0;
     }
  }
  if (digitalRead(2) == LOW)
  {
    lcd.clear();
    start = micros();
    lcd.print("Started...");
    while( ( analogRead(A1) > (ifRead2/2.0) ) && (counter < 35000) && digitalRead(2)==LOW ) 
    {
      counter = counter+1;
    }
      
    lcd.clear();
    if (digitalRead(2) == HIGH)
    {
      lcd.clear();
      lcd.print("Reset...");
      delay(2500);
    }
    else if (counter < 35000)
    {
      stop1 = micros(); 
      calculated = (5.000/12.000) / (((stop1 - start) / 1000000.00));
      lcd.print(calculated);
      lcd.setCursor(5,0);
      lcd.print("FPS");
      delay(2500);
    }    
    else
    {
      lcd.print("error");
      delay(1000);
    }
  
  }
  else
  {
    lcd.clear();
    lcd.print("Reset...");
    delay(1000);
  }
} 

//void loop() 
//{
//   
//   lcd.clear();
//   ifRead1=analogRead(A0); 
//   lcd.print("Sensor 1:       ");
//   lcd.setCursor(10,0);
//   lcd.print(ifRead1);  // Print a message to the LCD.
//   //delay(tim);
//
//   ifRead2=analogRead(A1);
//   lcd.setCursor(0,1);
//   lcd.print("Sensor 2:       ");
//   lcd.setCursor(10,1);
//   lcd.print(ifRead2);  // Print a message to the LCD.
//   delay(tim);
//   
//}

/************************************************************/

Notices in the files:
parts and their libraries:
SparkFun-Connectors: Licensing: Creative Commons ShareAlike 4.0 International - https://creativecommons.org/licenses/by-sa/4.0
